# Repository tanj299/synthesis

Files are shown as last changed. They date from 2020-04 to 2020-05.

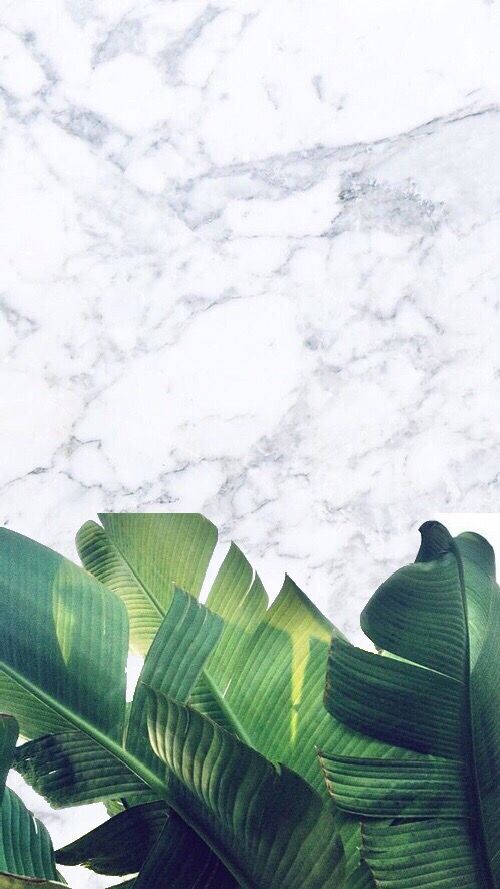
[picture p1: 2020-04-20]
flutter-app/assets/bgimg_overview.jpg

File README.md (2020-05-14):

# Synthesis
## Statement
## Last Updated: 05/9/2020
### Synthesis - The Automatic Garden
### Authors: Leo Au-Yeung, Stanley Lim, Daniel Mallia, Jayson Tan
### Deployed website: http://synthesis-garden.herokuapp.com/ ###

This repository contains the code developed by the above authors in the 
Spring 2020 CSCI Capstone course under Professor Maryash at Hunter College, for 
the purpose of running an automated garden with a web interface. The hardware
heart of the project is a Raspberry Pi 3 Model B gathering data on, and 
tending to, a physical garden via an Arduino with numerous sensors, a light 
and a water pump.

Both `garden_driver.py`, the script for the Raspberry Pi, and `garden.ino`,
the sketch for the Arduino, were designed and written for use on a 
"prepackaged" product, where the user does not require much technical
expertise. The user need only be able to determine what USB port they plugged 
a given Arduino into on the Raspberry Pi.

Recreating this project is not difficult but requires adhering to a couple of 
requirements:
- The same hardware must be used: Raspberry Pi 3 Model B, Arduino Uno, and the sensors described in the sensor tests sketches. It would not be difficult to adapt the software to other similar hardware but we make no guarantees that the existing software will work with different hardware. Note: the specs for the light and water pump do not impact the software. For reference, we used a 12V LED light (~500 mA) and a 12V dosing pump (~300 mA) both controlled by the Arduino via Songle relays rated for 28V 10A DC output.
- A backend must be deployed. Refer to the README in the backend folder for more information.
- What will not be obvious from the existing software is that two external configuration files are required in order to run the picture functionality. There should be a hidden folder in the home directory, `~/.aws/`, containing two files: `config` and `credentials`. 

`config` should contain (adjusting for your server configuration): 
```
[default]
region=us-east-1
```

`credentials` should contain (substituting for your server credentials):
```
[default]
aws_access_key_id = YOUR ID
aws_secret_access_key = YOUR KEY
```

Please refer to the [boto3 Quick Start guide](https://pypi.org/project/boto3/) and the [boto3 Documentation](https://boto3.amazonaws.com/v1/documentation/api/latest/index.html) for more information.

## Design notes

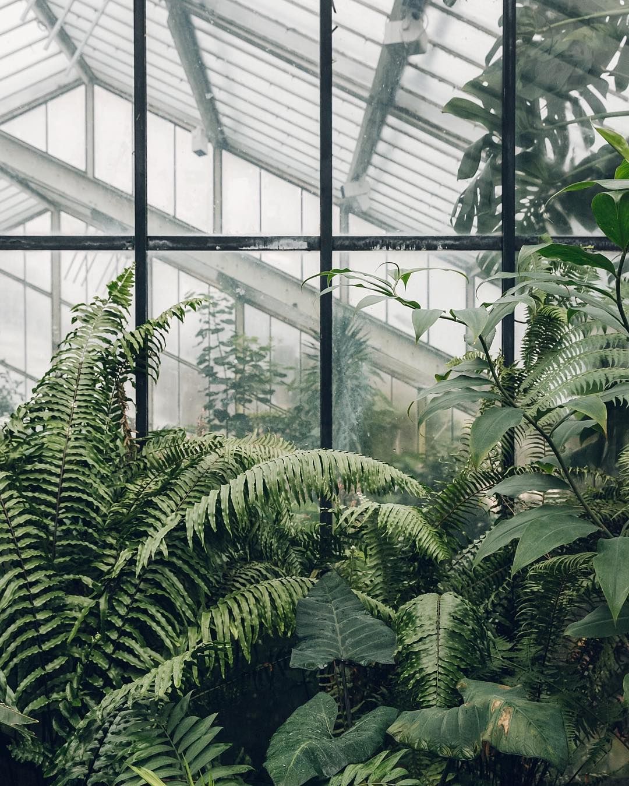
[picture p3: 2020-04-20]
flutter-app/assets/bgimg_dashboard.jpg

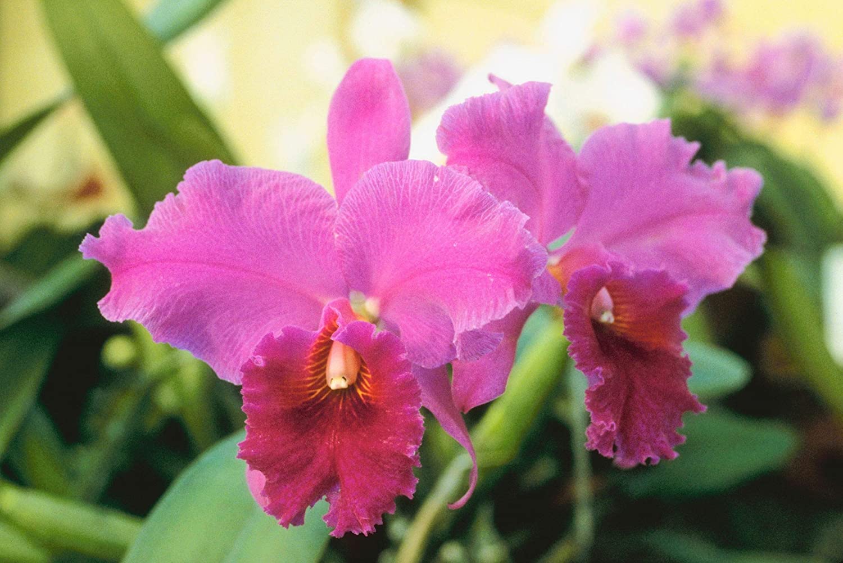
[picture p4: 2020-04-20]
flutter-app/assets/orchid.jpg

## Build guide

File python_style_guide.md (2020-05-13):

# Python Style Guide for Synthesis

### Author: Daniel Mallia
### Date Begun: 3/14/2020

The simple one-line rule is adhere to the PEP8 style guide, practicing sensical and readable Python. The most obvious and important rules are:

- Employ tabs, NOT spaces, of width 4. If using an editor which infers indentation from the existing document, this may not be an issue. For an editor like Vim, make sure to disable expandtab and set tab width to 4. 
- Use lower case variable names with underscores separating whole words. Ex: error_fan 
- Capitalize class names. Ex: Plant

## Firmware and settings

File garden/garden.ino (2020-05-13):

/*
 * Author:  Daniel Mallia
 * Date:    4/20/2020
 * Purpose: This is the main Arduino sketch for maintaining
 *          two plants in a synthesis garden.
 * 
 */

#include "Adafruit_Si7021.h"
#include <OneWire.h>
#include <DallasTemperature.h>

// Define sensors
// Single Temperature and Humidity Sensor
Adafruit_Si7021 th_sensor = Adafruit_Si7021();

// Single Water Level Sensor
const int water_lvl_sensor = 6;

// Set up OneWire objects
const int plant1_soil_temp_pin = 4;
const int plant2_soil_temp_pin = 5;
OneWire oneWire1(plant1_soil_temp_pin);
DallasTemperature plant1_soil_temp(&oneWire1);
DeviceAddress plant1_arr;
OneWire oneWire2(plant2_soil_temp_pin);
DallasTemperature plant2_soil_temp(&oneWire2);
DeviceAddress plant2_arr;

// Sensor arrays 
// Light (Analog) / Soil Moisture (Analog) 
int plant1_pins[] = {A0, A2};
int plant2_pins[] = {A1, A3};

// Define sensor constants
const float max_light = 4.80;
const float min_light = 0.01;
const float max_moisture = 1.71;
const float min_moisture = 0.90;

// Define relay control pins
const int light_ctrl = 8;
const int pump_ctrl = 10;

// Function to retrieve the light level as an integer
// percentage 0 - 100%
// Note: max and min are stored constants reflecting the 
// observed values with the sensor.
int get_light_level(int pin) {
  int raw = analogRead(pin);
  float voltage = (raw/1024.0) * 5.0;
  return round(100 * (1 - ((voltage - min_light) / (max_light - min_light))));
}

// Function to retrieve the moisture level as an integer
// percentage 0 - 100 %.
// Note: max and min are stored constants reflecting the 
// observed values with the sensor.
int get_moisture_level(int pin) {
  int sensorVal = analogRead(pin);
  float voltage = (sensorVal/1024.0) * 3.0;
  return round(100*( 1 - ((voltage - min_moisture) / (max_moisture - min_moisture))));
}

// Function for returning a "plant status report" over Serial.
// @param pins An array containing the pins for the plant of
//             interest, in the sensor ordering described above.
void plant_report(int pins[], DallasTemperature& sensor, DeviceAddress arr) {
  // Fetch temperature and humidity from the single Si7021 sensor
  int temp = round((1.8 * th_sensor.readTemperature()) + 32);
  delay(100);
  int humid = round(th_sensor.readHumidity());
  delay(100);

  // Fetch light reading
  int light = get_light_level(pins[0]);
  delay(100);

  // Fetch soil moisture
  int moisture = get_moisture_level(pins[1]);
  delay(100);

  // Fetch soil temperature
  sensor.requestTemperaturesByAddress(arr);
  int soil_temp = round(sensor.getTempF(arr));

  // Transmit over Serial as a comma-delimited sequence
  Serial.print(temp); Serial.print(","); Serial.print(humid);
  Serial.print(","); Serial.print(light); Serial.print(",");
  Serial.print(moisture); Serial.print(","); Serial.println(soil_temp);
}

int setup_soil_temp(DallasTemperature& sensor, DeviceAddress arr) {
  sensor.begin();
  if(!sensor.getAddress(arr, 0)) {
    return 1;
  } else {
    sensor.setResolution(arr, 10);
    return 0;
  }
}

void setup() {
  Serial.begin(9600);

  // Check for Si7021 sensor
  while (!th_sensor.begin()) {
    Serial.println("Did not find Si7021 sensor!");
    delay(5000);
    if(th_sensor.begin()) {
      break;
    }
  }

  // Set outputs and keep light and pump off unless requested
  pinMode(light_ctrl, OUTPUT);
  pinMode(pump_ctrl, OUTPUT);
  digitalWrite(light_ctrl, HIGH);
  digitalWrite(pump_ctrl, HIGH);
}

void loop() {
  // While there are commands to process
  while(Serial.available()) {
    char rec = Serial.read(); // Read command
    switch(rec) {
      case '1': // Report on plant 1
        plant_report(plant1_pins, plant1_soil_temp, plant1_arr); 
        break;
      case '2': // Report on plant 2
        plant_report(plant2_pins, plant2_soil_temp, plant2_arr); 
        break;
      case '3': // Check water level - return 0 if OK, else 1
        Serial.println(digitalRead(water_lvl_sensor));
        delay(100);
        break;
      case '4': // Set up plant 1 soil temperature sensor
        Serial.println(setup_soil_temp(plant1_soil_temp, plant1_arr));
        break;
      case '5': // Set up plant 2 soil temperature sensor
        Serial.println(setup_soil_temp(plant2_soil_temp, plant2_arr));
        break;
      case '6': // Turn on light
        digitalWrite(light_ctrl, LOW);
        break;
      case '7': // Turn off light
        digitalWrite(light_ctrl, HIGH);
        break;
      case '8': // Turn on pump
        digitalWrite(pump_ctrl, LOW);
        delay(100);
        break;
      case '9': // Turn off pump
        digitalWrite(pump_ctrl, HIGH);
        delay(100);
        break;
    }
  }

  delay(2000); // Rest for 2 seconds
}

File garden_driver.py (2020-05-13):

#! /usr/bin/env python3

# Authors: Daniel Mallia and Jayson Tan
# Date Begun: 3/14/2020

# This is the Python script intended to run on a Raspberry Pi and serve as
# the guiding "brain" of a synthesis garden's operation. It is called 
# garden_driver for this reason as well as because it acts as a software 
# driver, communicating with the actual hardware components.

import sys, time, argparse
import serial
import requests
from pynput import keyboard
from picamera import PiCamera
from io import BytesIO
import boto3

# GLOBALS
run_program=True
plants = {}     # Addresses Plant instances by plant ID (integer)
arduinos = {}   # Address arduinos (Serial objects) by port name (string)
HOST = "http://backend-dev222222.us-east-1.elasticbeanstalk.com/"
BUCKET = "elasticbeanstalk-us-east-1-813224974598"

class Plant():
	def __init__(self, name, id, arduino, position, water_threshold,
		light_threshold):
		self.name = name
		self.id = id
		
		if(arduino in arduinos):
			self.arduino = arduinos[arduino]
		else:
			try:
				arduinos[arduino] = serial.Serial(arduino, timeout=5)
			except serial.SerialException:
				print("Could not establish connection on port: ", arduino)
				print("Please check that the port name is correct and the ",
					"port is otherwise not in use.")
				cleanup()
			self.arduino = arduinos[arduino]
			time.sleep(10)

		self.position = position
		self.water_threshold = water_threshold
		self.light_threshold = light_threshold
		self.watered_today = False

		# Data
		# Lists are used for averaging values taken over the previous hour
		self.data_dict = {'temp': [], 'humidity': [], 'light': [],
			'soil_moisture': [], 'soil_temp': []}
		self.water_level = False # True = sufficient water
		self.light_on = False

		# Initialize soil temp sensor
		if(self.position == '1'):
			self.arduino.write(b'4')
		else:
			self.arduino.write(b'5')

		response = self.arduino.readline()
		response = response.decode("ascii").rstrip('\r\n')
		if(response == "" or response == "1"):
			print("Could not set up soil temperature sensor for plant: ",
				self.name)

		# Check water level
		self.check_water_level()

	# Returns True if watering was successful, else False
	def water(self):
		self.check_water_level()

		if(self.water_level):
			self.arduino.write(b'8')
			time.sleep(5)
			self.arduino.write(b'9')
			return True
		else:
			print("Could not water plant: ", self.name)
			return False

	def check_water_level(self):
		self.arduino.write(b'3')
		response = self.arduino.readline()
		response = response.decode("ascii").rstrip('\r\n')
		if(response == "" or response == "1"):
			self.water_level = False
		elif(response == "0"):
			self.water_level = True

	def toggle_light(self):
		if(self.light_on): # Turn off light
			self.arduino.write(b'7')
			self.light_on = False
		else: # Turn on light
			self.arduino.write(b'6')
			self.light_on = True

		# Update neighbor plant (same arduino) status
		for plant in plants:
			if(plants[plant].arduino == self.arduino):
				plants[plant].light_on = self.light_on

	def get_info(self):
		# Send position (1 or 2) to request information for respective position
		self.arduino.write(self.position.encode(encoding="ascii"))

		# Read and decode response
		data = self.arduino.readline()
		data = data.decode("ascii")

		# If data received, update attributes and return True, else return False
		data = data.rstrip('\r\n').split(',')
		if(len(data) == 5):
			self.data_dict['temp'].append(int(data[0]))
			self.data_dict['humidity'].append(int(data[1]))
			self.data_dict['light'].append(int(data[2]))
			self.data_dict['soil_moisture'].append(int(data[3]))
			self.data_dict['soil_temp'].append(int(data[4]))
			return True

		return False

	# Function to average out existing data, empty data lists, and prepare a report
	# Returns a dictionary ready for posting as a log
	def get_report(self):
		self.check_water_level()

		data = {
			'plant_id': self.id,
			'timestamp': "",
			'water_level': self.water_level,
			'light_status': self.light_on
		}

		for key in self.data_dict:
			if(len(self.data_dict[key]) == 0):
				return 1

			data[key] = round(sum(self.data_dict[key]) / len(self.data_dict[key]))
			self.data_dict[key].clear()
		return data

# Keyboard listener callback
# If the user presses q, change run_program to False
def on_press(key):
	global run_program

	if(hasattr(key,'char') and key.char == 'q'):
		run_program = False
		return False # Stop listener

	return True # Do not stop listener


# Function to print greeting screen, request login information and authorize 
# (acquire API access token)
def greet_and_login():
	# Greeting screen
	line = ('*' * 80) + '\n'
	blank = ' ' * 30
	print(line, line, '\n', blank, 'Welcome to SYNTHESIS', blank, '\n\n', line,
		line, 'Created by Leo Au-Yeung, Stanley Lim, Daniel Mallia and Jayson',
			' Tan\nHunter College, Spring 2020\n\n', sep ='')

	# Check library versions:
	print("Python version: ", sys.version)
	print("Serial library version: ", serial.__version__, "\n\n")

	# Request login information
	email = input('Enter your account email: ')
	password = input('Enter your account password: ')

	# Authorize - EXPAND TO CHECKING LOOP WHEN AUTHORIZATION SET UP
	token = ''

	print("Press q to quit the program.")

	return email, token

# Check user configuration and update script accordingly
# Returns true/false to enable different behavior in response to failed
# communication.
def configure(email):
	r = requests.get(HOST + "plants/all/" + email + "/")

	if(r.status_code != 200):
		print("Could not retrieve user configuration.")
		return False
	else:
		active_plant_ids = []
		for entry in r.json():
			id = entry["plant_id"]
			active_plant_ids.append(id)
			if(id not in plants): # Add plant
				name = entry["plant_name"]
				port = entry["serial_port"]
				position = str(entry["position"])
				water_threshold = entry["water_threshold"]
				light_threshold = entry["light_threshold"]
				plants[id] = Plant(name, id, port, position, water_threshold,
					light_threshold)
				print("Added plant: " + name)
				request_email(id, "new")
			else: # Update plant
				plants[id].name = entry["plant_name"]
				plants[id].water_threshold = entry["water_threshold"]
				plants[id].light_threshold = entry["light_threshold"]

		# Check for plant deletions
		for plant in plants:
			if plant not in active_plant_ids:
				del plants[plant]

	return True

# Function to request emails for plant added or empty water
# id is the plant id, and case is either "new" or "water"
def request_email(id, case):
	r = requests.get(HOST + "alert/" + str(id) + "/" + case)
	if(r.status_code != 200):
		print("Request for email failed.")

# Function to cleanly exit the program
def cleanup():
	print("Stopping...")

	# Turn off lights and close all Serial connections
	for arduino in arduinos:
		arduinos[arduino].write(b'7')
		arduinos[arduino].close()

	print("Please reset and unplug your arduinos!")
	sys.exit()
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

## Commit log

2020-03-31 Fix typos and expand on hardware dictionary
    [garden_driver.py]
2020-04-05 Add soil temp schematic as fzz and png
    [soil_temp_test_schematic.fzz]
2020-04-05 Add soil moisture schematic as fzz and png
    [soil_moisture_test_schematic.fzz]
2020-04-06 Add print Python version
2020-04-06 Add sensors dictionary, additional flag, and stub for parsing configuration
2020-04-13 Add pump relay schematics
    [pump_relay_test_schematic.fzz]
2020-04-13 Add pump_relay_test sketch
2020-04-16 Add light test schematic
    [light_test_schematic.fzz]
2020-04-16 Add water level test schematic
    [water_level_test_schematic.fzz]
2020-04-20 Add camera_test.py
2020-04-20 Add single_arduino_schematic with Si7021 sensor
    [single_arduino_schematic.fzz]
2020-04-20 Reorient schematic and add light sensors
    [single_arduino_schematic.fzz]
2020-04-20 Add soil temperature sensors
    [single_arduino_schematic.fzz]
2020-04-20 Added liquid level sensor
    [single_arduino_schematic.fzz]
2020-04-20 Revise sensors and add humidity
2020-04-23 Add soil temperature ability
2020-04-23 Correct soil temperature signal connections and remove light digital
    [single_arduino_schematic.fzz]
2020-04-26 Add support for light and pump
2020-04-30 Add updated backend 4/29, add ability to sign out, add water plant button call to /requests
2020-05-02 Correct indentation on function
    [garden_driver.py]
2020-05-03 Update backend 5/3, add in buttons for light, picture, update button for water
2020-05-03 Minor text fixes - aligning success/error text on camera/light/water button press
2020-05-03 Add correct requests for configuration and commands, correct cleanup
    [garden_driver.py]
2020-05-06 Add assorted fixes and error checking
    [garden_driver.py]
2020-05-07 Add picture functionality and correct cleanup usage
    [garden_driver.py]
2020-05-11 Add delete button, view plant logs button, popup functionality for plant logs
2020-05-13 Rename args and add debugging printing
2020-05-13 Add error checking for failure to gen report
    [garden_driver.py]
2020-05-13 Add additional debugging printing and adjust automatic behavior
2020-05-13 Change Arduino rest time to 2 seconds
